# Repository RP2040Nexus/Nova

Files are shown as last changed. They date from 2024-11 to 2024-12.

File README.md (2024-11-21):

# Nova



Nova is a super tiny [RP2040](https://www.raspberrypi.com/products/rp2040/) board featuring an integrated 7x10 addressable LED matrix. This project aims to provide an easy-to-use platform for creating interactive and visually engaging projects.

## Table of Contents

- [Features](#features)
- [Getting Started](#getting-started)
- [Arduino IDE Installation](#arduino-ide-installation)
- [Pinouts](#pinouts)

## Features

- Compact size: Easy to integrate into various projects
- [RP2040](https://www.raspberrypi.com/products/rp2040/) microcontroller: Powerful and efficient
- Integrated 7x10 addressable LED matrix ([WS2812-1010](https://www.mouser.com/datasheet/2/744/WS2812B_1010_DATASHEET-3314306.pdf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))

## Getting Started

To get started with Nova, you'll need the following:

- [Nova Board](link_to_Nova_Product_Page)
- [Arduino IDE](https://www.arduino.cc/en/software)
- Compatible power source (USB Type-C, battery, etc.)

## Pinouts
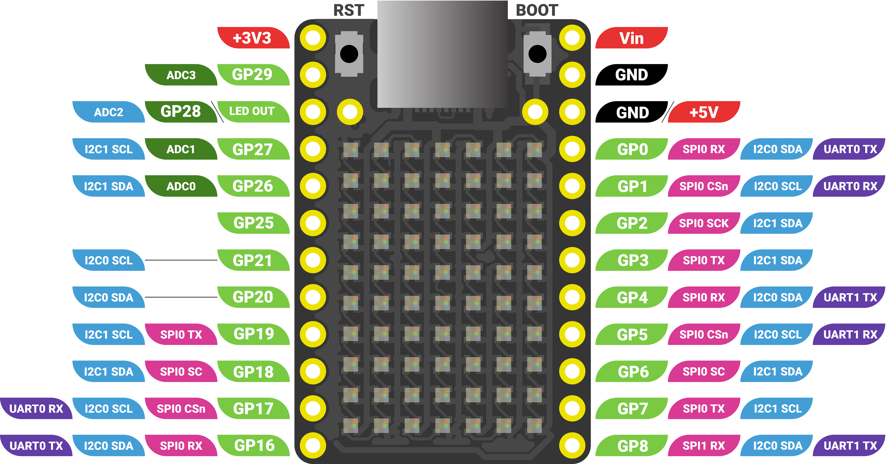
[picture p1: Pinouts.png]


## Arduino IDE Installation

### Adding Nova Board to Arduino IDE

1. **Open Arduino IDE**: Launch the Arduino IDE on your computer.

2. **Open Preferences**: 
   - Go to `File` -> `Preferences` (or `Arduino IDE` -> `Preferences` on macOS).

3. **Add Board URL**:
   - In the Preferences window, find the `Additional Boards Manager URLs` field. 
   - Add the following URL to the field:
     ```
     https://github.com/earlephilhower/arduino-pico/releases/download/global/package_rp2040_index.json
     ```
   - If there are already other URLs, separate them with commas.

4. **Open Boards Manager**:
   - Go to `Tools` -> `Board` -> `Boards Manager`.

5. **Install RP2040 Core**:
   - In the Boards Manager window, type `RP2040` in the search box.
   - Look for `Raspberry Pi Pico/RP2040 by Earle Philhower` and click the `Install` button.

6. **Select the Nova Board**:
   - Once the installation is complete, go to `Tools` -> `Board` and select `Raspberry Pi Pico`.

7. ### Install Required Libraries

- It is recommended to use the **FastLED** library for controlling the LED matrix.

#### Installing FastLED Library

1. **Open Library Manager**:
   - Go to `Sketch` -> `Include Library` -> `Manage Libraries...`.

2. **Search for FastLED**:
   - In the Library Manager window, type `FastLED` in the search bar.

3. **Install FastLED**:
   - Find the **FastLED** library ([Repo](https://github.com/FastLED/FastLED)) and click the `Install` button.
  
#### Using FastLED with Nova

Here’s a basic example of how to use the FastLED library to control a single LED on your Nova board:

```cpp
#include <FastLED.h>

#define LED_PIN     22    // Data pin connected to LED0 (GP22)
#define NUM_LEDS    1      // Total number of LEDs (only LED0)

CRGB leds[NUM_LEDS];

void setup() {
    FastLED.addLeds<WS2812, LED_PIN, GRB>(leds, NUM_LEDS);
    FastLED.setBrightness(10); // Set brightness to 10 out of 255
}

void loop() {
    // Example: Set LED0 to red color
    leds[0] = CRGB::Red;
    FastLED.show();
    delay(1000);
    
    // Example: Turn off LED0
    leds[0] = CRGB::Black;
    FastLED.show();
    delay(1000);
}

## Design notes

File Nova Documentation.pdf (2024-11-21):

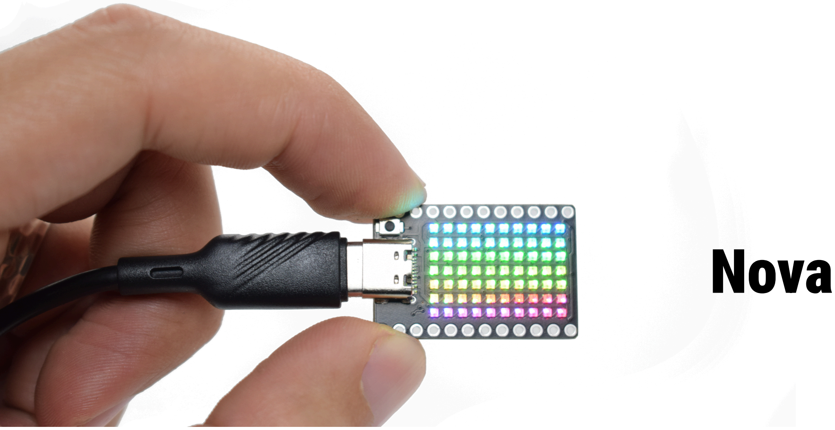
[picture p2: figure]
Nova

## 1. Introduction

The Nova board is an RP2040-based development board designed for engineers, developers, and embedded enthusiasts. With its powerful dual-core ARM Cortex M0+ processor and integrated 7x10 LED matrix, Nova offers a compact and versatile platform for various applications.

The board is open-source hardware, making it easy to customize and extend for your specific needs.

## 2. Features

- Microcontroller: Raspberry Pi RP2040 with dual ARM Cortex M0+ cores running up to 133 MHz.
- Memory: 264KB of SRAM, with support for external flash 16M-bit (2M-byte).
- 7x10 LED Matrix: Integrated with 70 RGB LEDs (addressable WS2812).
- GPIO: Accessible for various I/O purposes.
- Power Input: Via USB Type-C or external power.
- Connectivity: USB and various standard GPIO pins for communication protocols (I2C, SPI, UART).
- Open-source: Fully customizable hardware with publicly available schematics and examples.

## 3. Getting Started

### 3.1 Setting Up Your Development Environment

To start developing with the Nova board, follow these steps:

1. Install the Arduino IDE (https://www.arduino.cc/en/software) (or VSCode with the PlatformIO extension).
- Download the latest version from Arduino's website.
- For PlatformIO, follow the guide here. (https://docs.platformio.org/en/latest/platforms/raspberrypi.html)
2. Install the RP2040 Board Package:
- In the Arduino IDE, go to File > Preferences.
- Under Additional Boards Manager URLs, paste this URL:

https://github.com/earlephilhower/arduino-pico/releases/download/global/package_rp2040_index.json

- Open the Boards Manager and search for "RP2040." Install the package.
3. Install the FastLED Library:
- In the Arduino IDE, go to Sketch > Include Library > Manage Libraries.
- Search for "FastLED" and install it, (any other suitable library for the WS2812 LEDs can also be used such as Neopixel). (https://github.com/adafruit/Adafruit_NeoPixel)
4. Connect the Nova Board:
- Plug in the Nova board via the USB Type-C connector.
- Select the Nova board from the Tools > Board menu in the Arduino IDE.
- Choose the correct port under Tools > Port.

### 3.2 Hello World: Blink Example

Let's begin with a simple LED blink example:

#include <FastLED.h> // Include the FastLED library to control the LED matrix

#define DATA_PIN 22 // Define the pin where the LED matrix is connected (GPIO22)

#define NUM_LEDS 70 // Define the number of LEDs in the matrix (7x10 = 70)

CRGB leds[NUM_LEDS]; // Create an array to store the color data for each LED

void setup() {
// Initialize the LED matrix using the NEOPIXEL type and link it to the data pin
// FastLED.addLeds<CHIPSET, DATA_PIN>(led array, number of LEDs); FastLED.addLeds<NEOPIXEL, DATA_PIN>(leds, NUM_LEDS);
}

void loop() {
leds[0] = CRGB::Red; | // Set LED 0 (top-right corner) to red
FastLED.show(); | // Send the data to the LED matrix to display the
change
delay(500); | // Wait for 500 milliseconds (half a second)

leds[0] = CRGB::Black; // Turn off LED 0 (set it to black)

FastLED.show(); | // Update the LED matrix to show the change
delay(500); | // Wait for 500 milliseconds before repeating the
loop
}

Upload the code to your Nova board, and you should see the first LED (top right corner) blinking!

## 4. LED Matrix Layout

The Nova board comes with a 7x10 LED matrix. Here’s how the LEDs are arranged:

- Rows: The matrix is divided into rows, each containing 10 LEDs.
- Addressing: The LEDs are numbered from 0 to 69. The first row (LED0 to LED9) runs from right to left, while the second row (LED10 to LED10) runs from left to right, and so on.

Here's a quick reference:

LED9 | LED8 | LED7 | LED6 | LED5 | LED4 | LED3 | LED2 | LED1 | LED0
LED10 | LED11 | LED12 | LED13 | LED14 | LED15 | LED16 | LED17 | LED18 | LED19
LED29 | LED28 | LED27 | LED26 | LED25 | LED24 | LED23 | LED22 | LED21 | LED20
LED30 | LED31 | LED32 | LED33 | LED34 | LED35 | LED36 | LED37 | LED38 | LED39
LED49 | LED48 | LED47 | LED46 | LED45 | LED44 | LED43 | LED42 | LED41 | LED40
LED50 | LED51 | LED52 | LED53 | LED54 | LED55 | LED56 | LED57 | LED58 | LED59
LED69 | LED68 | LED67 | LED66 | LED65 | LED64 | LED63 | LED62 | LED61 | LED60

### 4.1 Displaying Custom Patterns

You can use the FastLED library to control the matrix. Here's an example to display the letter 'C' on the left side of the matrix:

#include <FastLED.h>

#define DATA_PIN 22

#define NUM_LEDS 70

CRGB leds[NUM_LEDS];

void setup() {
FastLED.addLeds<NEOPIXEL, DATA_PIN>(leds, NUM_LEDS); FastLED.clear(); // Clear the LED matrix
}

void loop() {
displayLetterC(); // Display the smaller letter 'C' on the matrix
FastLED.show(); | // Update the LED matrix
delay(5000); | // Hold the letter 'C' for 5 seconds
}

void displayLetterC() {
// Small 'C' that fits in 4 rows and 3 columns

// Left vertical column of 'C'
leds[9] = CRGB::Green; // Row 0
leds[10] = CRGB::Green; // Row 1 leds[29] = CRGB::Green; // Row 2 leds[30] = CRGB::Green; // Row 3

// Top part of 'C' (Row 0) leds[8] = CRGB::Green;
leds[7] = CRGB::Green;

// Bottom part of 'C' (Row 3) leds[31] = CRGB::Green;
leds[32] = CRGB::Green;
}
LED9 | LED8 | LED7 | LED6 | LED5 | LED4 | LED3 | LED2 | LED1 | LED0
LED10 | LED11 | LED12 | LED13 | LED14 | LED15 | LED16 | LED17 | LED18 | LED19
LED29 | LED28 | LED27 | LED26 | LED25 | LED24 | LED23 | LED22 | LED21 | LED20
LED30 | LED31 | LED32 | LED33 | LED34 | LED35 | LED36 | LED37 | LED38 | LED39
LED49 | LED48 | LED47 | LED46 | LED45 | LED44 | LED43 | LED42 | LED41 | LED40
LED50 | LED51 | LED52 | LED53 | LED54 | LED55 | LED56 | LED57 | LED58 | LED59
LED69 | LED68 | LED67 | LED66 | LED65 | LED64 | LED63 | LED62 | LED61 | LED60

## 6. Pinout

- Data Pin for LED Matrix: GPIO22
- Other key GPIO pins are exposed for various I/O tasks. Please refer to the pinout diagram for detailed pin functions:

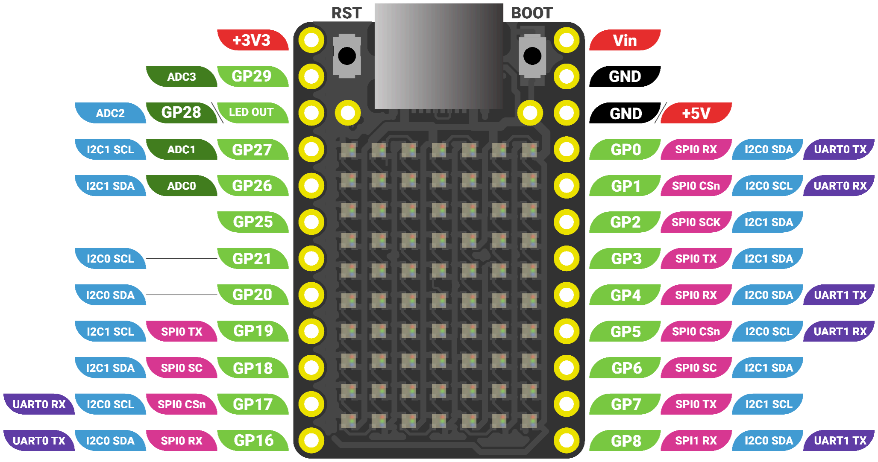
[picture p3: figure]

## 7. Powering the Board and Power Consumption

Power Regulation:

- Nova has two regulators: a buck converter and an LDO (linear regulator).
- The buck converter handles input voltages from 7VDC to 18VDC via the Vin pin and provides 5VDC for the circuit, which is needed for the addressable LEDs.
- The LDO takes the 5VDC from either the buck converter or USB and regulates it down to 3.3VDC for the RP2040 and other 3.3V components.

Powering the Board:

- The board can be powered via:
- Vin pin: Accepts 7-18VDC.
- +5V pin: Accepts 4.8-5.2VDC.
- +3V3 pin is not meant to power the whole board, only the MCU (without LEDs).

Power Output from +5V Pin:

- When powered by the Vin pin, the +5V pin can provide up to 1.2A.
- When powered by USB, the +5V pin can provide up to 150mA.

+3V3 Pin:

- The recommended maximum current draw from the +3V3 pin is 150mA in all cases.

Power Consumption
The Nova board consumes approximately 9 watts when all LEDs are at full brightness in white color. It’s recommended to avoid running all LEDs at maximum brightness for extended periods, as this can cause the board to overheat, potentially leading to
damage to the board or its components.

## 8. Schematics and Hardware

The Nova board is open-source hardware. You can find the schematics, PCB design files, and BOM (Bill of Materials) on our GitHub (https://github.com/VccLabs/Nova) repository.

## 9. Troubleshooting

Common Issues

1. Board not recognized:
- Ensure that the USB cable is working and data-capable.
- Check if the correct port and board are selected in the Arduino IDE.
2. LEDs not lighting up:
- Verify that the data pin is identified in the code properly (GPIO22).
- Make sure the FastLED library is installed and included in your sketch (any other suitable library for the WS2812 LEDs can also be used such as Neopixel). (https://github.com/adafruit/Adafruit_NeoPixel)
- You can enter bootloader mode using the ‘Boot’ button. To do this, hold down the 'Boot' button (located to the right of the USB port) while connecting the board to your PC via USB. This will put the board into bootloader mode and open a mass storage window on your computer. This is useful if the board is not being detected by the PC.

## 10. Contact & Support

For further questions or support, you can reach us at support@vcclabs.com. Join our community on GitHub and check out the forums for more resources and user projects.

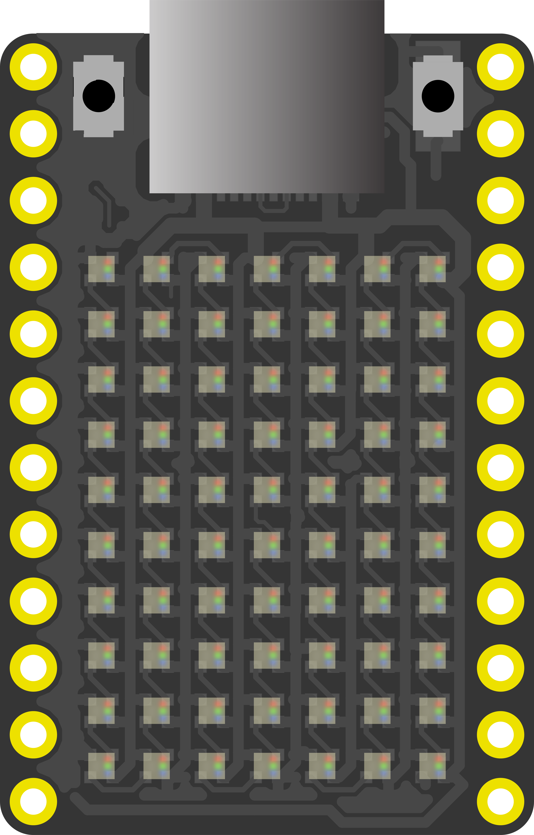
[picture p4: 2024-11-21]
Illustrations/Board Illustration.png

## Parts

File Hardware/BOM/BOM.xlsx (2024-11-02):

Comment | Designator | Footprint | Manufacturer Part #
Miltilayer Ceramic Capacitor 100nF | C1,C2,C9 | 0402 | CL05B104KB54PNC
Miltilayer Ceramic Capacitor 10uF | C3,C4,C5,C6,C7,C11,C33 | 0603 | GRM188R6YA106MA73D
Miltilayer Ceramic Capacitor 27pF | C8,C10 | 0402 | CC0402JRNPO9BN270
Miltilayer Ceramic Capacitor 120pF | C12 | 0402 | CC0402JRNPO9BN121
Miltilayer Ceramic Capacitor 12nF | C13 | 0402 | GRM155R71H123KA12D
SMD,1x1mm RGB LEDs(Built-in IC) ROHS | D1,D2,D3,D4,D5,D6,D7,D8,D9,D10,D11,D12,D13,D14,D15,D16,D17,D18,D19,D20,D21,D22,D23,D24,D25,D26,D27,D28,D29,D30,D31,D32,D33,D34,D35,D36,D37,D38,D39,D40,D41,D42,D43,D44,D45,D46,D47,D48,D49,D50,D51,D52,D53,D54,D55,D56,D57,D58,D59,D60,D61,D62,D63,D64,D65,D66,D67,D68,D69,D70 | SMD,1x1mm | XL-1010RGBC-WS2812B
USON-8-EP(2x3) NOR FLASH ROHS | IC1 | USON-8-EP(2x3) | W25Q16JVUXIQ
1A 4.7uH ±20% 130mΩ 1008 Inductors (SMD) ROHS | L1,L2,L3 | 1008 | MLP2520S4R7MT0S1
50V 220mA 3.5Ω@10V,220mA 360mW 1.5V@1mA 1PCSNChannel SOT-23 MOSFETs ROHS | Q3 | SOT-23 | BSS138
SMD Chip Resistor 3.74K | R1 | 0402 | 0402WGF3741TCE
SMD Chip Resistor 1K | R3,R4 | 0402 | 0402WGF1001TCE
SMD Chip Resistor 10K | R5,R8,R9,R32 | 0402 | 0402WGF1002TCE
SMD Chip Resistor 27.4 | R6,R7 | 0402 | ARG02FTC27R4
SMD Chip Resistor 220K | R14 | 0402 | RC0402FR-07220KL
SMD Chip Resistor 43.2K | R15 | 0402 | RT0402FRE0743K2L
SMD Chip Resistor 100K | R16 | 0402 | RC0402FR-07100KL
SMD Chip Resistor 19.1K | R17 | 0402 | 0402WGF1912TCE
SMD Chip Resistor 51.1 | R18 | 0402 | SCR0402F51R1
SMD Chip Resistor 143K | R19 | 0402 | FRC0402F1433TS
2.5mm 1.6mm Round Button 50mA Standing paste 3mm SPST 153gf 12V SMD,2.5x3mm Tactile Switches ROHS | S1 | SMD,2.5x3mm | B3U-1000P
Step-down type Adjustable 800mV~24V 3A 4.5V~28V VSON-10-EP(3x3) DC-DC Converters ROHS | U1 | VSON-10-EP(3x3) | TPS54335ADRCR
65dB@(100Hz,1kHz) 600mA Fixed 3.3V Positive electrode 6V SOT-25-5 Voltage Regulators - Linear, Low Drop Out (LDO) Regulators ROHS | U2 | SOT-25-5 | AP2112K-3.3TRG1
264KB 30 133MHz LQFN-56(7x7) Microcontrollers (MCU/MPU/SOC) ROHS | U3 | LQFN-56(7x7) | RP2040
TYPEC-304-ACP16 | USBC | TYPEC-304-ACP16 | TYPEC-304-ACP16
12MHz SMD Crystal Resonator 18pF 150Ω ±10ppm ±30ppm -40℃~+85℃ SMD2520-4P Crystals ROHS | Y2 | SMD2520-4P | 2TJ412000XYGBC

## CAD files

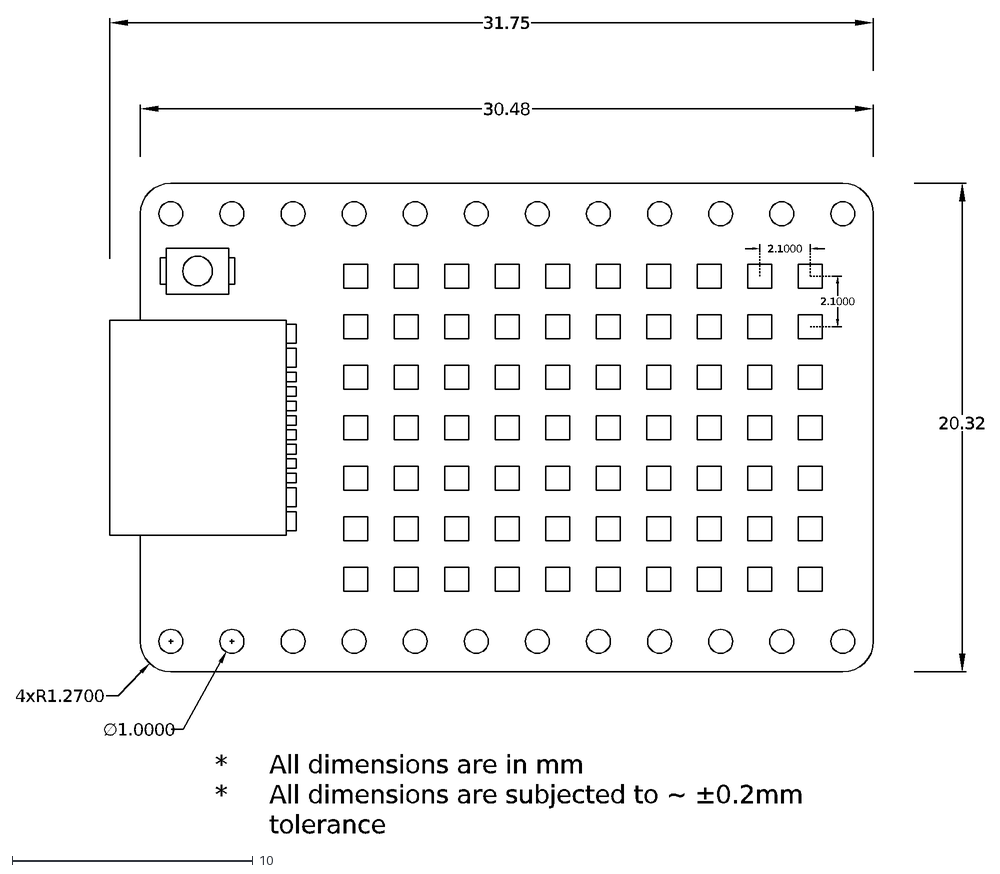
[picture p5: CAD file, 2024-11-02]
Hardware/Board Dimensions & DXF/Board DXF.dxf
30.48
20.32
4xR1.2700
∅1.0000
2.1000
31.75
* All dimensions are in mm * All dimensions are subjected to ~ ±0.2mm tolerance

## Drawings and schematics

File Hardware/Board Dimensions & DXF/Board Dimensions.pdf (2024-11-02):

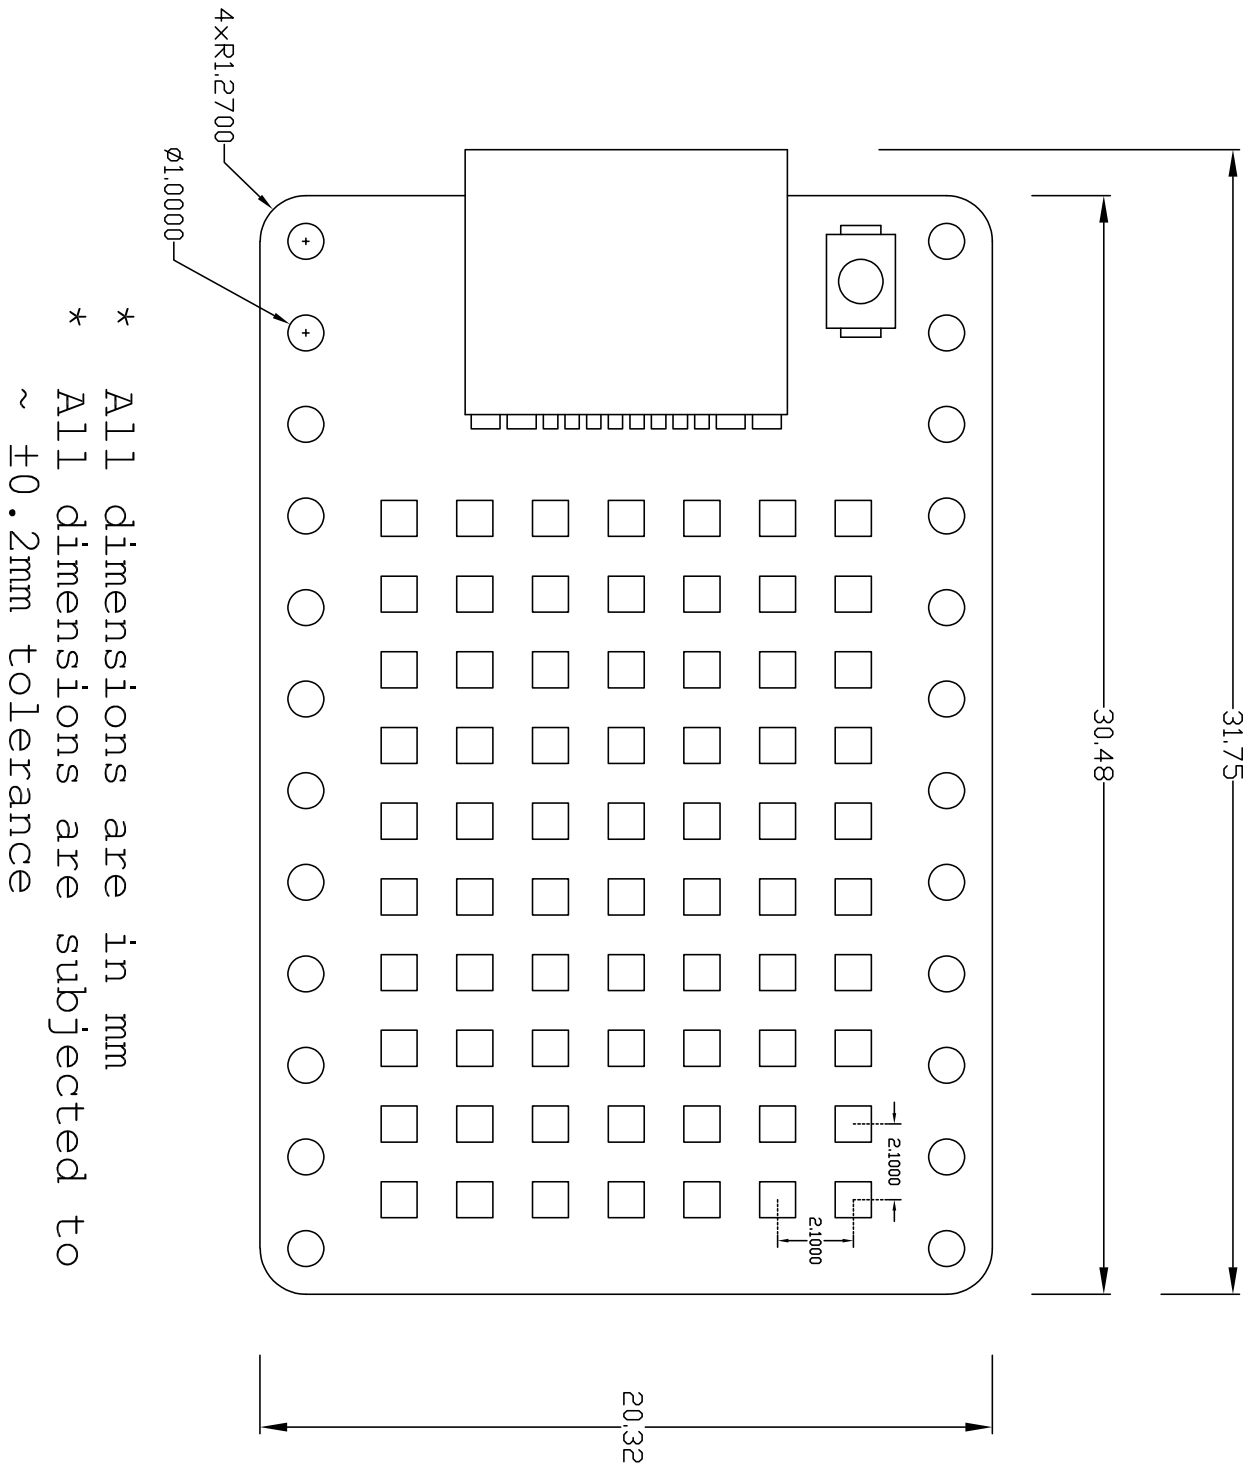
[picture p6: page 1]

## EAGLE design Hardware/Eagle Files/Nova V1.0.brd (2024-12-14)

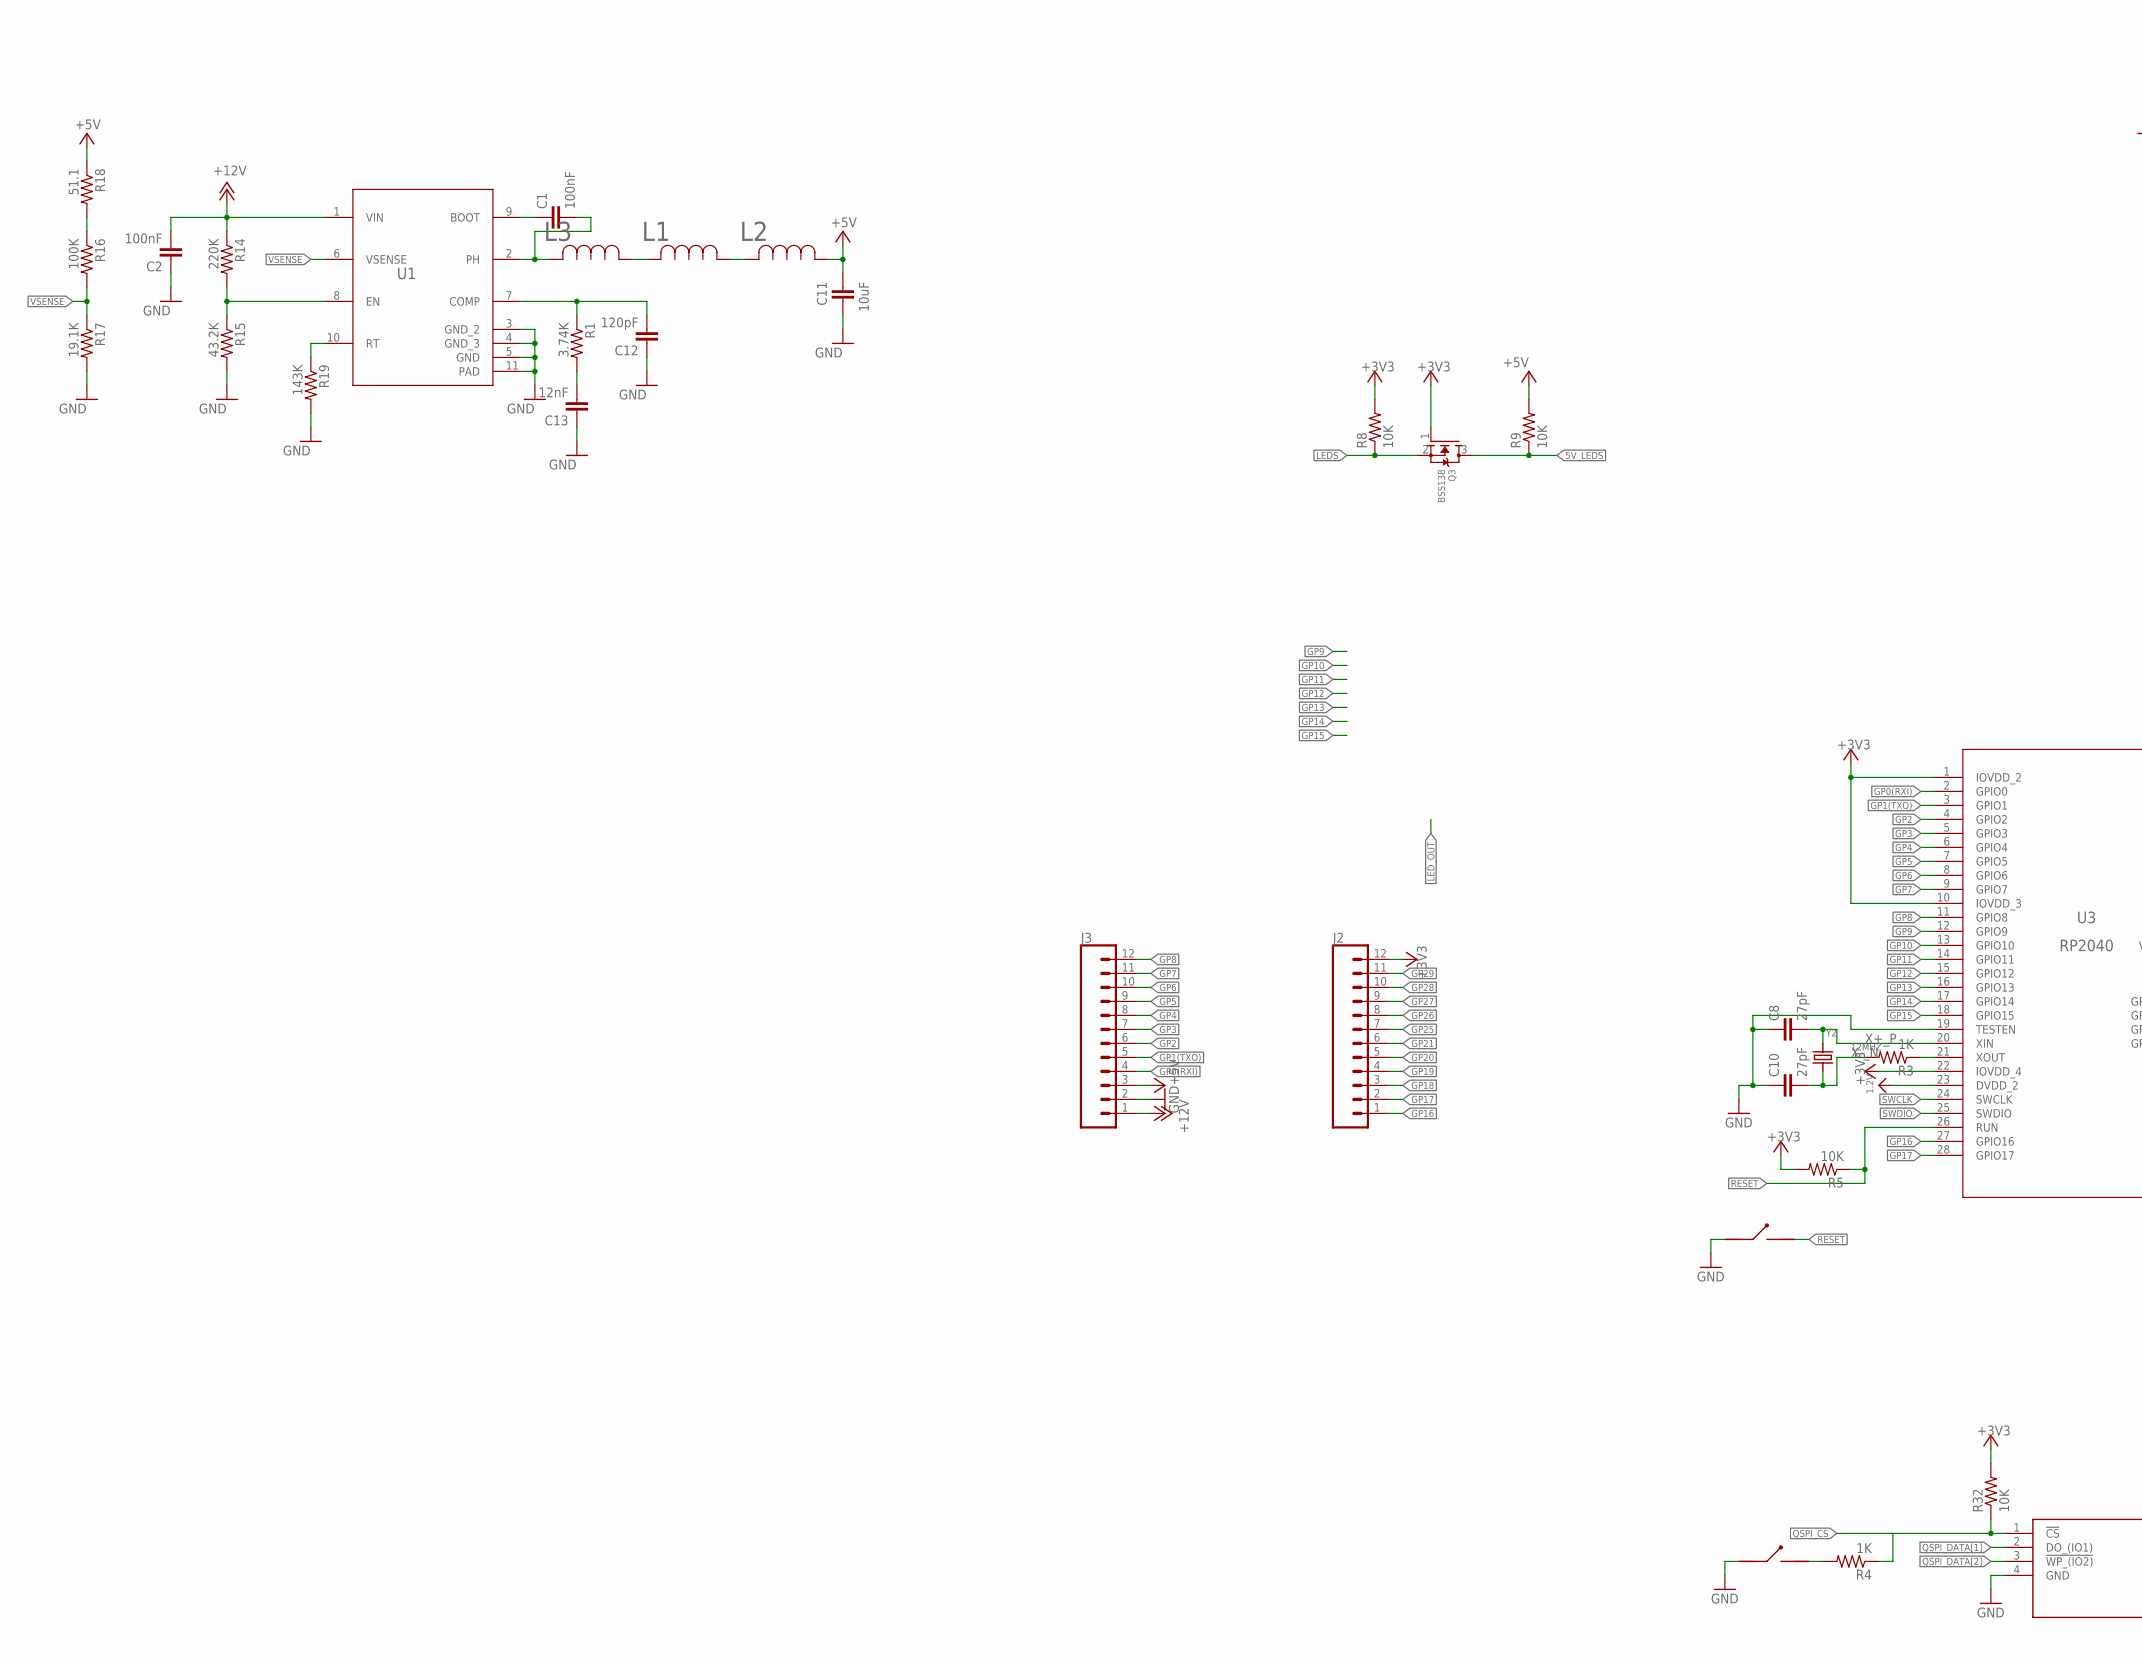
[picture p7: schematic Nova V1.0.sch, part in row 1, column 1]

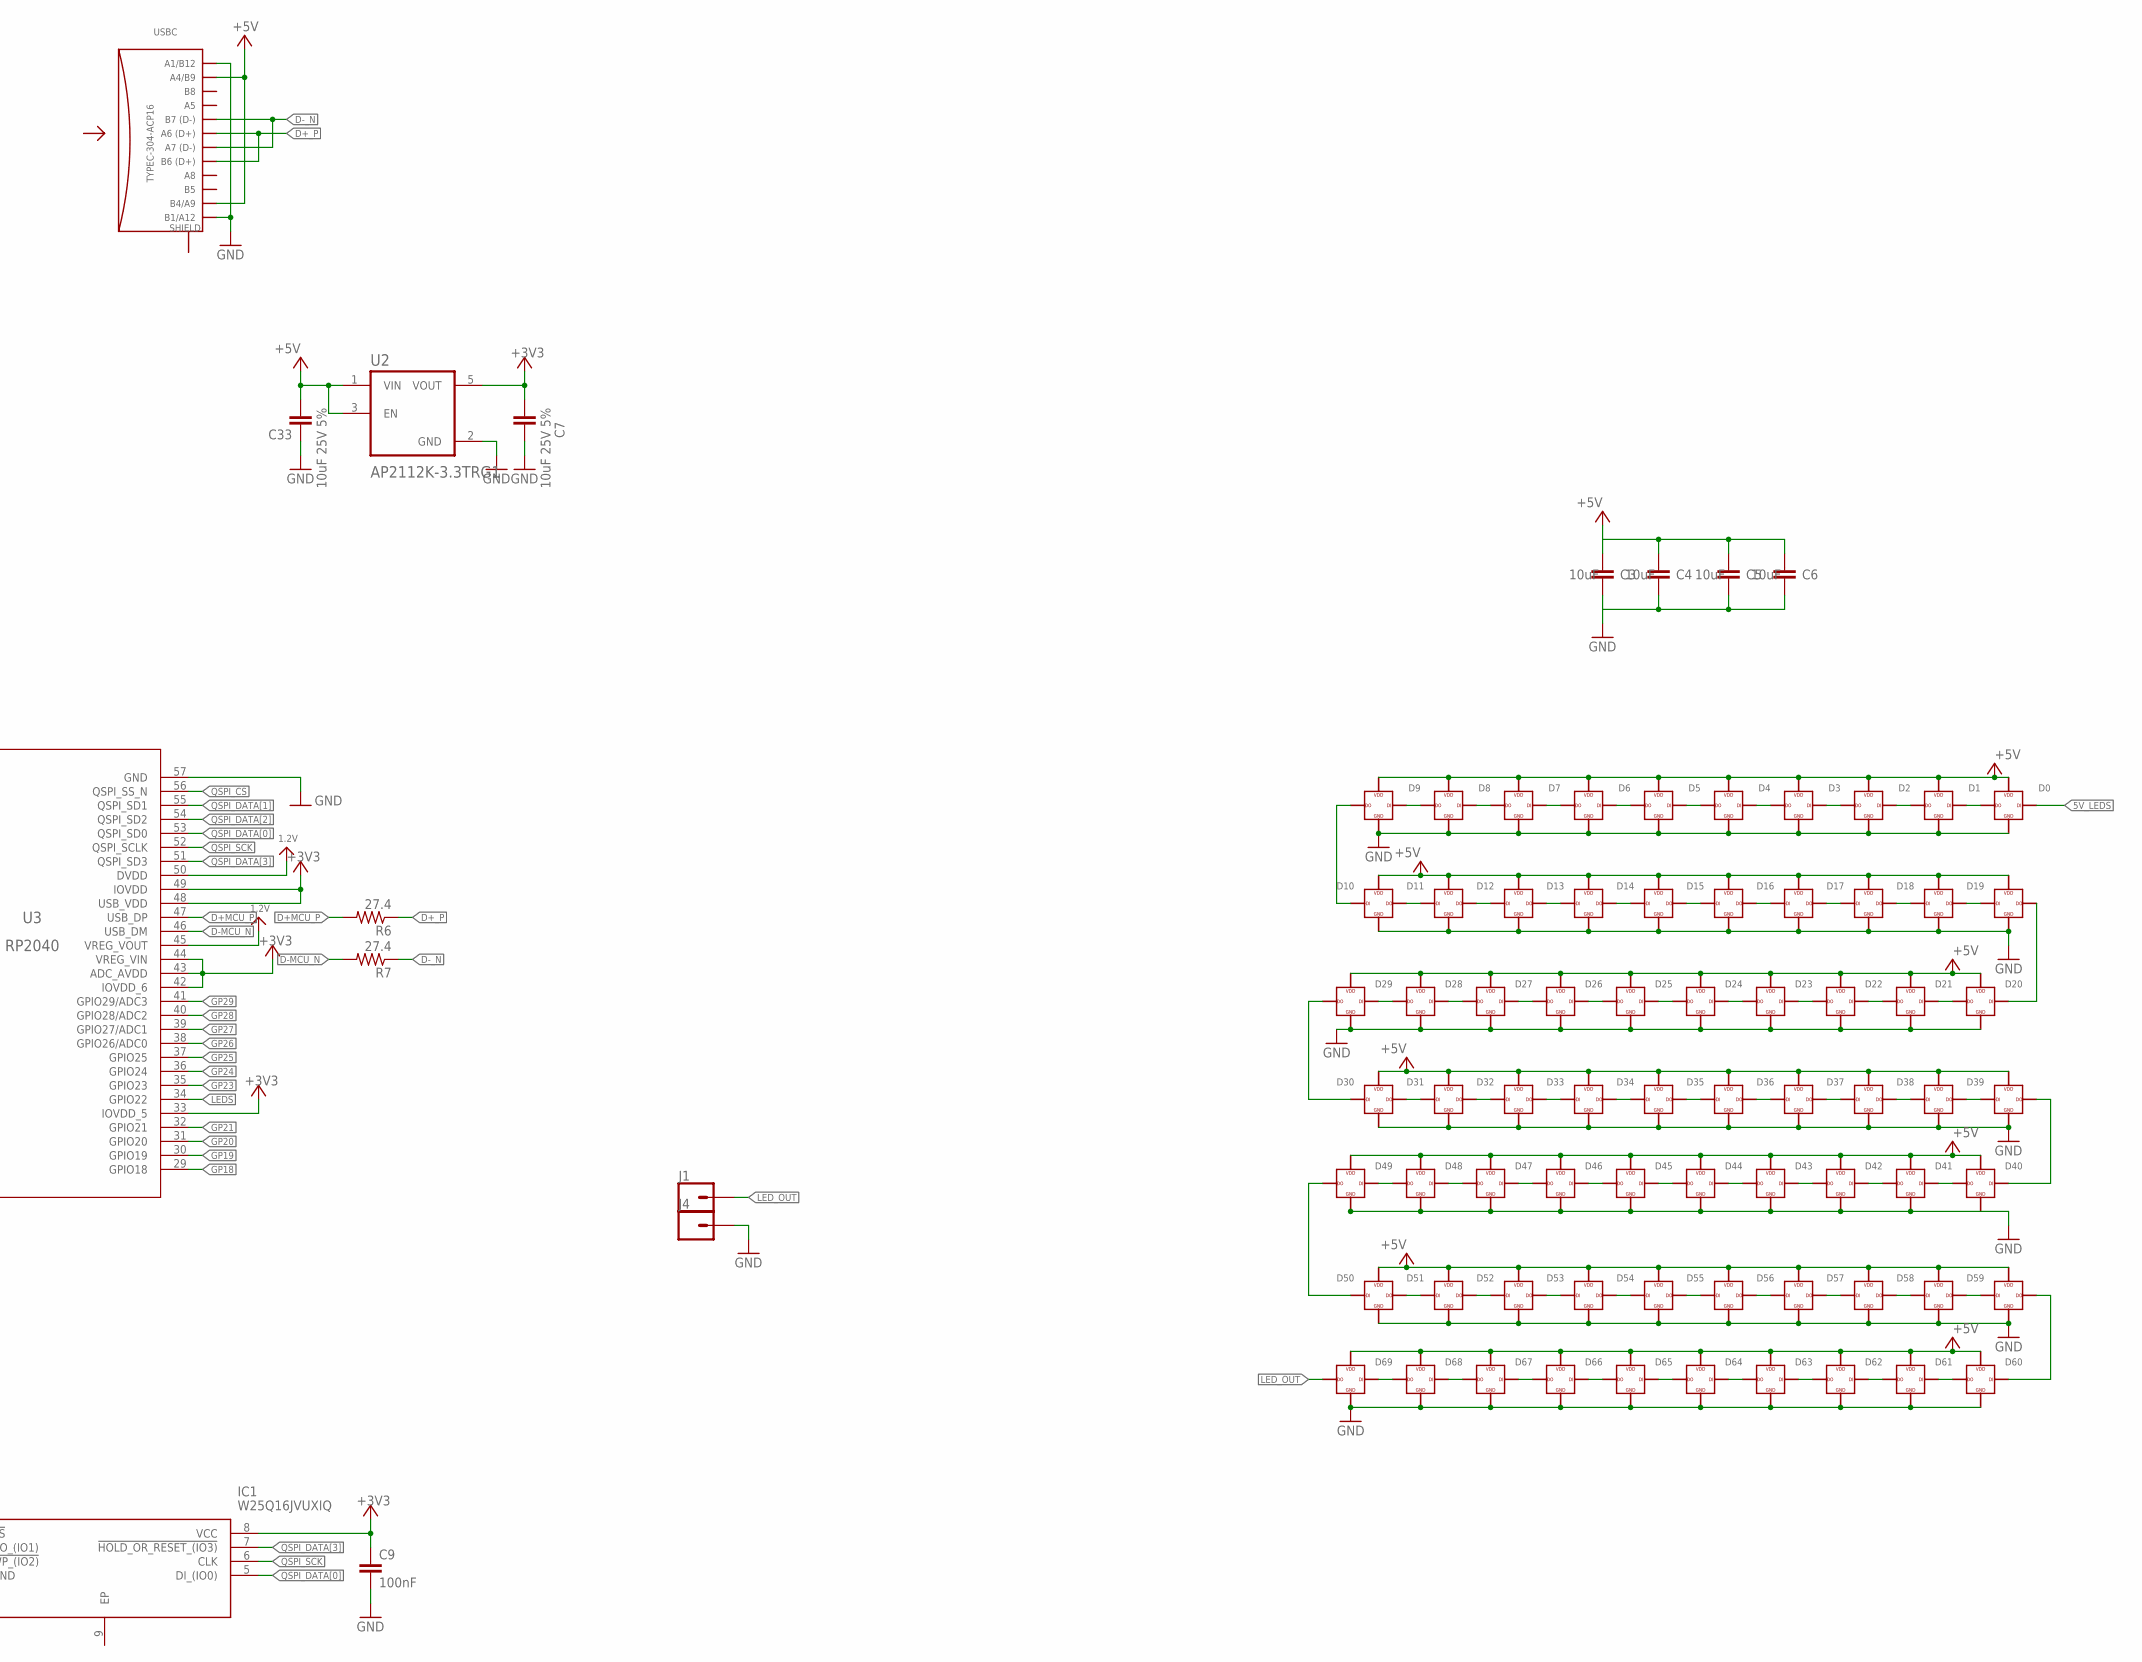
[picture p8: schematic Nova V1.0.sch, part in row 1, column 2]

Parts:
C1, C2, C9: 100nF; 0402-TIGHT
C3, C4, C5, C6, C11: 10uF; C0603
C7, C33: 10uF 25V 5%; C0603
C8, C10: 27pF; 0402-TIGHT
C12: 120pF; 0402-TIGHT
C13: 12nF; 0402-TIGHT
D0, D1, D2, D3, D4, D5, D6, D7, D8, D9, D10, D11, D12, D13, D14, D15, D16, D17, D18, D19, D20, D21, D22, D23, D24, D25, D26, D27, D28, D29, D30, D31, D32, D33, D34, D35, D36, D37, D38, D39, D40, D41, D42, D43, D44, D45, D46, D47, D48, D49, D50, D51, D52, D53, D54, D55, D56, D57, D58, D59, D60, D61, D62, D63, D64, D65, D66, D67, D68, D69: XL-1010RGBC-WS2812B
IC1: W25Q16JVUXIQ; SON50P300X200X60-9N
J1, J4: CONN_01; 1X01
J2, J3: CONN_12; 1X12
L1, L2, L3: MLP2520S4R7MT0S1IND_2520_TDK-L; IND_2520_TDK-L
Q3: BSS138; SOT23
R1: 3.74K; R0402
R3, R4: 1K; R0402
R5, R8, R9, R32: 10K; R0402
R6, R7: 27.4; R0402
R14: 220K; R0402
R15: 43.2K; R0402
R16: 100K; R0402
R17: 19.1K; R0402
R18: 51.1; R0402
R19: 143K; R0402
S1, S2: B3U-1000P
U1: TPS54335ADRCRDRC0010J_NV; DRC0010J_NV
U2: AP2112K-3.3TRG1; SOT95P285X140-5N
U3: RP2040; IC57_RP2040
USBC: TYPEC-304-ACP16
Y2: 12MHZ; CRYSTAL_2.5X2

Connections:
1.2V: U3.23 (DVDD_2), U3.45 (VREG_VOUT), U3.50 (DVDD)
5V_LEDS: D0.4, Q3.3 (D), R9.1
+3V3: C7.2, C9.1, IC1.8 (VCC), J2.12, Q3.1 (G), R5.2, R8.2, R32.2, U2.5 (VOUT), U3.1 (IOVDD_2), U3.10 (IOVDD_3), U3.22 (IOVDD_4), U3.33 (IOVDD_5), U3.42 (IOVDD_6), U3.43 (ADC_AVDD), U3.44 (VREG_VIN), U3.48 (USB_VDD), U3.49 (IOVDD)
+5V: C3.1, C4.1, C5.1, C6.1, C11.2, C33.2, D0.2, D1.2, D2.2, D3.2, D4.2, D5.2, D6.2, D7.2, D8.2, D9.2, D10.2, D11.2, D12.2, D13.2, D14.2, D15.2, D16.2, D17.2, D18.2, D19.2, D20.2, D21.2, D22.2, D23.2, D24.2, D25.2, D26.2, D27.2, D28.2, D29.2, D30.2, D31.2, D32.2, D33.2, D34.2, D35.2, D36.2, D37.2, D38.2, D39.2, D40.2, D41.2, D42.2, D43.2, D44.2, D45.2, D46.2, D47.2, D48.2, D49.2, D50.2, D51.2, D52.2, D53.2, D54.2, D55.2, D56.2, D57.2, D58.2, D59.2, D60.2, D61.2, D62.2, D63.2, D64.2, D65.2, D66.2, D67.2, D68.2, D69.2, J3.3, L2.1, R9.2, R18.1, U2.1 (VIN), U2.3 (EN), USBC.A4/B9, USBC.B4/A9
+12V: C2.2, J3.1, R14.1, U1.1 (VIN)
D+MCU_P: R6.2, U3.47 (USB_DP)
D+_P: R6.1, USBC.A6, USBC.B6
D-MCU_N: R7.2, U3.46 (USB_DM)
D-_N: R7.1, USBC.A7, USBC.B7
GND: C2.1, C3.2, C4.2, C5.2, C6.2, C7.1, C8.1, C9.2, C10.1, C11.1, C12.1, C13.1, C33.1, D0.3, D1.3, D2.3, D3.3, D4.3, D5.3, D6.3, D7.3, D8.3, D9.3, D10.3, D11.3, D12.3, D13.3, D14.3, D15.3, D16.3, D17.3, D18.3, D19.3, D20.3, D21.3, D22.3, D23.3, D24.3, D25.3, D26.3, D27.3, D28.3, D29.3, D30.3, D31.3, D32.3, D33.3, D34.3, D35.3, D36.3, D37.3, D38.3, D39.3, D40.3, D41.3, D42.3, D43.3, D44.3, D45.3, D46.3, D47.3, D48.3, D49.3, D50.3, D51.3, D52.3, D53.3, D54.3, D55.3, D56.3, D57.3, D58.3, D59.3, D60.3, D61.3, D62.3, D63.3, D64.3, D65.3, D66.3, D67.3, D68.3, D69.3, IC1.4 (GND), J3.2, J4.1, R15.2, R17.2, R19.2, S1.1, S2.1, U1.3 (GND_2), U1.4 (GND_3), U1.5 (GND), U1.11 (PAD), U2.2 (GND), U3.19 (TESTEN), U3.57 (GND), USBC.A1/B12, USBC.B1/A12
GP0(RXI): J3.4, U3.2 (GPIO0)
GP1(TXO): J3.5, U3.3 (GPIO1)
GP2: J3.6, U3.4 (GPIO2)
GP3: J3.7, U3.5 (GPIO3)
GP4: J3.8, U3.6 (GPIO4)
GP5: J3.9, U3.7 (GPIO5)
GP6: J3.10, U3.8 (GPIO6)
GP7: J3.11, U3.9 (GPIO7)
GP8: J3.12, U3.11 (GPIO8)
GP9: U3.12 (GPIO9)
GP10: U3.13 (GPIO10)
GP11: U3.14 (GPIO11)
GP12: U3.15 (GPIO12)
GP13: U3.16 (GPIO13)
GP14: U3.17 (GPIO14)
GP15: U3.18 (GPIO15)
GP16: J2.1, U3.27 (GPIO16)
GP17: J2.2, U3.28 (GPIO17)
GP18: J2.3, U3.29 (GPIO18)
GP19: J2.4, U3.30 (GPIO19)
GP20: J2.5, U3.31 (GPIO20)
GP21: J2.6, U3.32 (GPIO21)
GP23: U3.35 (GPIO23)
GP24: U3.36 (GPIO24)
GP25: J2.7, U3.37 (GPIO25)
GP26: J2.8, U3.38 (GPIO26/ADC0)
GP27: J2.9, U3.39 (GPIO27/ADC1)
GP28: J2.10, U3.40 (GPIO28/ADC2)
GP29: J2.11, U3.41 (GPIO29/ADC3)
LEDS: Q3.2 (S), R8.1, U3.34 (GPIO22)
LED_OUT: D69.1, J1.1
unnamed: D0.1, D1.4
unnamed: D1.1, D2.4
unnamed: D2.1, D3.4
unnamed: D3.1, D4.4
unnamed: D4.1, D5.4
unnamed: D5.1, D6.4
unnamed: D6.1, D7.4
unnamed: D7.1, D8.4
unnamed: D8.1, D9.4
unnamed: D9.1, D10.4
unnamed: D10.1, D11.4
unnamed: D11.1, D12.4
unnamed: D12.1, D13.4
unnamed: D13.1, D14.4
unnamed: D14.1, D15.4
unnamed: D15.1, D16.4
unnamed: D16.1, D17.4
unnamed: D17.1, D18.4
unnamed: D18.1, D19.4
unnamed: D19.1, D20.4
unnamed: D20.1, D21.4
unnamed: D21.1, D22.4
unnamed: D22.1, D23.4
unnamed: D23.1, D24.4
unnamed: D24.1, D25.4
unnamed: D25.1, D26.4
unnamed: D26.1, D27.4
unnamed: D27.1, D28.4
unnamed: D28.1, D29.4
unnamed: D29.1, D30.4
unnamed: D30.1, D31.4
unnamed: D31.1, D32.4
unnamed: D32.1, D33.4
unnamed: D33.1, D34.4
unnamed: D34.1, D35.4
unnamed: D35.1, D36.4
unnamed: D36.1, D37.4
unnamed: D37.1, D38.4
unnamed: D38.1, D39.4
unnamed: D39.1, D40.4
unnamed: D40.1, D41.4
unnamed: D41.1, D42.4
unnamed: D42.1, D43.4
unnamed: D43.1, D44.4
unnamed: D44.1, D45.4
unnamed: D45.1, D46.4
unnamed: D46.1, D47.4
unnamed: D47.1, D48.4
unnamed: D48.1, D49.4
unnamed: D49.1, D50.4
unnamed: D50.1, D51.4
unnamed: D51.1, D52.4
unnamed: D52.1, D53.4
unnamed: D53.1, D54.4
unnamed: D54.1, D55.4
unnamed: D55.1, D56.4
unnamed: D56.1, D57.4
unnamed: D57.1, D58.4
unnamed: D58.1, D59.4
unnamed: D59.1, D60.4
unnamed: D60.1, D61.4
unnamed: D61.1, D62.4
unnamed: D62.1, D63.4
unnamed: D63.1, D64.4
unnamed: D64.1, D65.4
unnamed: D65.1, D66.4
unnamed: D66.1, D67.4
unnamed: D67.1, D68.4
unnamed: D68.1, D69.4
unnamed: R3.1, U3.21 (XOUT)
unnamed: R4.2, S1.2
unnamed: C1.1, U1.9 (BOOT)
unnamed: L1.2, L3.1
unnamed: L1.1, L2.2
unnamed: C13.2, R1.2
unnamed: C12.2, R1.1, U1.7 (COMP)
unnamed: R14.2, R15.1, U1.8 (EN)
unnamed: R16.1, R18.2
unnamed: R19.1, U1.10 (RT)
PH: C1.2, L3.2, U1.2 (PH)
QSPI_CS: IC1.1 (!CS), R4.1, R32.1, U3.56 (QSPI_SS_N)
QSPI_DATA[0]: IC1.5 (DI_(IO0)), U3.53 (QSPI_SD0)
QSPI_DATA[1]: IC1.2 (DO_(IO1)), U3.55 (QSPI_SD1)
QSPI_DATA[2]: IC1.3 (!WP_(IO2)), U3.54 (QSPI_SD2)
QSPI_DATA[3]: IC1.7 (!HOLD_OR_RESET_(IO3)), U3.51 (QSPI_SD3)
QSPI_SCK: IC1.6 (CLK), U3.52 (QSPI_SCLK)
RESET: R5.1, S2.2, U3.26 (RUN)
SWCLK: U3.24 (SWCLK)
SWDIO: U3.25 (SWDIO)
VSENSE: R16.2, R17.1, U1.6 (VSENSE)
X+_P: C8.2, U3.20 (XIN), Y2.3 (2)
X-_N: C10.2, R3.2, Y2.1

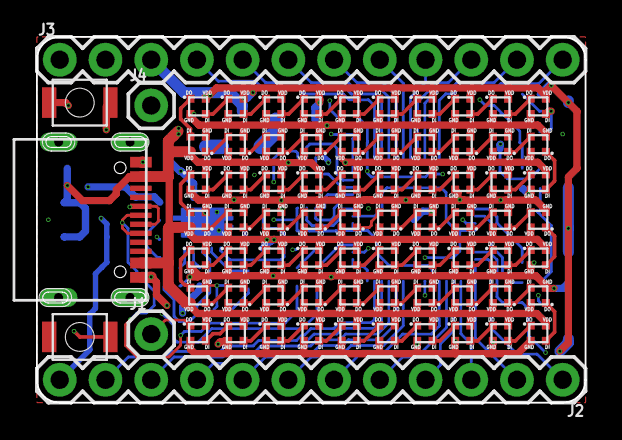
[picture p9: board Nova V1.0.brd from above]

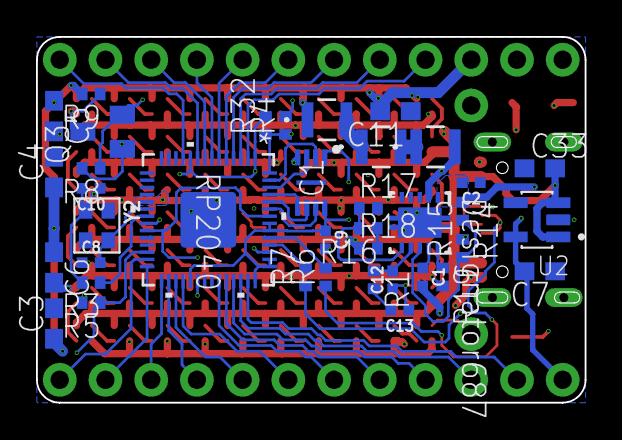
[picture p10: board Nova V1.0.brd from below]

Board: 4 copper layers, 30.5 x 20.3 mm, 115 parts (38 on the bottom side), 122 nets.

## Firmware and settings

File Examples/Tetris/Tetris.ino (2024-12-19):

/*
 * Tetris Game Example for Nova Board
 *
 * Button Connections:
 * - UP Button: connected to pin 2
 * - LEFT Button: connected to pin 3
 * - DOWN Button: connected to pin 4
 * - RIGHT Button: connected to pin 5
 * - RESET Button: connected to pin 6
 *
 * Note: External pull-down resistors are used with the buttons to ensure stable readings.
 *
 * License:
 * This project is open-source hardware and software, released under the MIT License.
 * See the LICENSE file for details.
 */


#include <FastLED.h>

#define LED_PIN 22
#define NUM_LEDS 70
#define BRIGHTNESS 10

CRGB leds[NUM_LEDS];

// Matrix layout
const int matrix[10][7] = {
    {69, 50, 49, 30, 29, 10, 9},
    {68, 51, 48, 31, 28, 11, 8},
    {67, 52, 47, 32, 27, 12, 7},
    {66, 53, 46, 33, 26, 13, 6},
    {65, 54, 45, 34, 25, 14, 5},
    {64, 55, 44, 35, 24, 15, 4},
    {63, 56, 43, 36, 23, 16, 3},
    {62, 57, 42, 37, 22, 17, 2},
    {61, 58, 41, 38, 21, 18, 1},
    {60, 59, 40, 39, 20, 19, 0}
};

// Button pins
const int upButtonPin = 2;
const int leftButtonPin = 3;
const int downButtonPin = 4;
const int rightButtonPin = 5;
const int generalButtonPin = 6;

// Tetromino shapes
const int shapes[7][4][1] = {
    // I
    {{1}, {1}, {1}, {1}},
    // O
    {{1}, {1}, {0}, {0}},
    // T
    {{0}, {1}, {1}, {0}},
    // J
    {{1}, {1}, {1}, {0}},
    // L
    {{0}, {0}, {1}, {1}},
    // S
    {{0}, {1}, {1}, {0}},
    // Z
    {{1}, {1}, {0}, {0}},
};

// Game variables
int currentShapeIndex;
int currentX, currentY;

// Game state
bool board[10][7] = {false};

unsigned long lastUpdate = 0; // Variable to store the last update time
const unsigned long updateInterval = 300; // Game update interval

const unsigned long debounceDelay = 250; // Debounce time in milliseconds
unsigned long lastPressTime[5] = {0}; // Array to store the last pressed time for each button

void setup() {
    Serial.begin(115200);
    FastLED.addLeds<WS2812, LED_PIN, GRB>(leds, NUM_LEDS).setCorrection(TypicalLEDStrip);
    FastLED.setBrightness(BRIGHTNESS);



    // Start a new game
    startNewGame();
}

void loop() {
    readButtons(); // Check for button presses

    unsigned long currentMillis = millis(); // Get the current time
    // Check if it's time to update the game state
    if (currentMillis - lastUpdate >= updateInterval) {
        moveDown(); // Move the piece down
        drawBoard(); // Draw the updated board
        
        lastUpdate = currentMillis; // Update the last update time
    }
    FastLED.show(); // Update the LED strip
}

void startNewGame() {
    // Reset the board state
    memset(board, false, sizeof(board)); // Clear the board
    resetPiece(); // Get a new piece
}



void readButtons() {
    unsigned long currentMillis = millis(); // Get the current time

    // Right button
    if (digitalRead(rightButtonPin) == HIGH && (currentMillis - lastPressTime[0] >= debounceDelay)) {
        lastPressTime[0] = currentMillis; // Update the last pressed time
        movePiece(1, 0); // Move right
    }

    // Left button
    if (digitalRead(leftButtonPin) == HIGH && (currentMillis - lastPressTime[1] >= debounceDelay)) {
        lastPressTime[1] = currentMillis; // Update the last pressed time
        movePiece(-1, 0); // Move left
    }

    // Up button (rotate piece - not implemented)
    if (digitalRead(upButtonPin) == HIGH && (currentMillis - lastPressTime[2] >= debounceDelay)) {
        lastPressTime[2] = currentMillis; // Update the last pressed time
        // Rotate piece (not implemented)
    }

    // Down button
    if (digitalRead(downButtonPin) == HIGH && (currentMillis - lastPressTime[3] >= debounceDelay)) {
        lastPressTime[3] = currentMillis; // Update the last pressed time
        moveDown(); // Move down
    }

    // General button (restart game)
    if (digitalRead(generalButtonPin) == HIGH && (currentMillis - lastPressTime[4] >= debounceDelay)) {
        lastPressTime[4] = currentMillis; // Update the last pressed time
        startNewGame(); // Restart the game
    }
}


void movePiece(int dx, int dy) {
    currentX += dx;
    currentY += dy;

    // Check for collisions
    if (checkCollision()) {
        currentX -= dx; // Undo move
        currentY -= dy; // Undo move
    }
}

void moveDown() {
    currentY++;
    if (checkCollision()) {
        currentY--; // Undo move
        lockPiece(); // Lock the piece
        resetPiece(); // Get a new piece
    }
}

void resetPiece() {
    currentShapeIndex = random(0, 7); // Choose a random shape
    currentX = 3; // Start in the middle
    currentY = 0; // Start at the top

    // Check for game over condition immediately after resetting
    if (checkCollision()) {
        startNewGame(); // Restart the game if collision with the top row occurs
    }
}

bool checkCollision() {
    for (int i = 0; i < 4; i++) {
        int ledX = currentX; 
        int ledY = currentY + (shapes[currentShapeIndex][i][0] == 1 ? i : 0); // Incrementing only for occupied cells

        // Check if out of bounds
        if (ledY >= 10 || ledX < 0 || ledX >= 7) return true; // Ensure within bounds

        // Check if position is occupied
        if (shapes[currentShapeIndex][i][0] == 1) {
            if (ledY < 10 && board[ledY][ledX]) return true; // Check if occupied
        }
    }
    return false; // No collision
}






void lockPiece() {
    for (int i = 0; i < 4; i++) {
        int ledX = currentX;
        int ledY = currentY + i;
        
        if (shapes[currentShapeIndex][i][0] == 1) {
            board[ledY][ledX] = true; // Lock the piece into the board
        }
    }
    clearLines(); // Check for full lines
}

void clearLines() {
    for (int i = 0; i < 10; i++) {
        bool fullLine = true;
        for (int j = 0; j < 7; j++) {
            if (!board[i][j]) {
                fullLine = false;
                break;
            }
        }
        
        if (fullLine) {
            // Display colorful line effect before clearing
            for (int effectTime = 0; effectTime < 20; effectTime++) { // Adjust duration of effect
                // Create a colorful moving line effect
                for (int j = 0; j < 7; j++) {
                    int ledIndex = matrix[i][j];
                    // Cycle through colors
                    leds[ledIndex] = CHSV((effectTime * 10 + j * 30) % 256, 255, 255); // Change colors
                }
                FastLED.show(); // Update the LED strip
                delay(10); // Adjust delay for speed of effect
            }

            // Shift lines down
            for (int k = i; k > 0; k--) {
                for (int j = 0; j < 7; j++) {
                    board[k][j] = board[k - 1][j];
                }
            }
            // Clear the top line
            for (int j = 0; j < 7; j++) {
                board[0][j] = false;
            }
        }
    }
}


void drawBoard() {
    clearLEDs();
    // Draw the locked pieces
    for (int i = 0; i < 10; i++) {
        for (int j = 0; j < 7; j++) {
            if (board[i][j]) {
                leds[matrix[i][j]] = CRGB::Red; // Color the locked piece
            }
        }
    }
    // Draw the current piece
    for (int i = 0; i < 4; i++) {
        int ledX = currentX;
        int ledY = currentY + i;
        if (shapes[currentShapeIndex][i][0] == 1 && ledY < 10) {
            leds[matrix[ledY][ledX]] = CRGB::Green; // Color the current piece
        }
    }
}

void clearLEDs() {
    for (int i = 0; i < NUM_LEDS; i++) {
        leds[i] = CRGB::Black; // Clear the LEDs
    }
}
// End of the code

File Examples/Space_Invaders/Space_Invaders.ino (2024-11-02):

/*
 * Space Invaders Game Example for Nova Board
 *
 * Button Connections:
 * - UP Button: connected to pin 2
 * - LEFT Button: connected to pin 3
 * - DOWN Button: connected to pin 4
 * - RIGHT Button: connected to pin 5
 * - RESET Button: connected to pin 6
 *
 * Note: External pull-down resistors are used with the buttons to ensure stable readings.
 *
 * License:
 * This project is open-source hardware and software, released under the MIT License.
 * See the LICENSE file for details.
 */
 
 
 #include <FastLED.h>

#define LED_PIN 22
#define NUM_LEDS 70
#define BRIGHTNESS 10

CRGB leds[NUM_LEDS];

// Define button pins
#define LEFT_BUTTON 3
#define RIGHT_BUTTON 5
#define RESTART_BUTTON 6

// Define game and missile speeds (in milliseconds)
int gameSpeed = 100; // Time interval for starship movement debounce
int missileSpeed = 30; // Time interval for missile movement
int fireInterval = 100; // Time between firing missiles
int enemySpeed = 150; // Speed of enemies moving down (increased for slower movement)
int enemySpeedAdjustment = 50; // Adjusting factor for enemy speed

// Starship position (starts in the middle of the bottom row)
int starshipPosition = 3; // Index for the bottom row (0-6)

// Define LED layout for each row of the matrix
const int rows[10][7] = {
    {69, 50, 49, 30, 29, 10, 9},
    {68, 51, 48, 31, 28, 11, 8},
    {67, 52, 47, 32, 27, 12, 7},
    {66, 53, 46, 33, 26, 13, 6},
    {65, 54, 45, 34, 25, 14, 5},
    {64, 55, 44, 35, 24, 15, 4},
    {63, 56, 43, 36, 23, 16, 3},
    {62, 57, 42, 37, 22, 17, 2},
    {61, 58, 41, 38, 21, 18, 1},
    {60, 59, 40, 39, 20, 19, 0} // Bottom row (starship row)
};

// Enemy positions and colors
const int maxEnemies = 1; // Maximum number of enemies at a time
int enemyRow[maxEnemies]; // Array to hold enemy row positions
int enemyPosition[maxEnemies]; // Array to hold enemy column positions
CRGB enemyColors[maxEnemies]; // Array to hold colors for enemies
bool enemyActive[maxEnemies]; // Array to hold the active state of enemies
unsigned long lastEnemyMoveTime = 0; // Timer for moving enemies

// Missile state
bool missileActive = false;
int missileRow = 8; // Start from row 8 (just above the starship)
int missilePosition = starshipPosition;
unsigned long lastFireTime = 0;
unsigned long lastMissileMoveTime = 0;
unsigned long lastStarshipMoveTime = 0; // Timer for the starship movement debounce

int tailLength = 3; // Length of the missile tail

// Function to clear the starship position
void clearStarship() {
    leds[rows[9][starshipPosition]] = CRGB::Black;
}

// Function to fire a missile
void fireMissile() {
    missileActive = true;
    missileRow = 8; // Start just above the starship in row 8
    missilePosition = starshipPosition;
}

// Function to clear the missile and its tail
void clearMissile() {
    // Clear the missile's position
    if (missileRow < 10) {
        leds[rows[missileRow][missilePosition]] = CRGB::Black; // Clear main missile
    }

    // Clear the tail
    for (int i = 0; i < tailLength; i++) {
        int clearRow = missileRow + i;
        if (clearRow < 10) { // Make sure we don’t go beyond the matrix
            leds[rows[clearRow][missilePosition]] = CRGB::Black; // Clear tail
        }
    }
}

// Function to move the missile upward with a comet-like tail that dims gradually
void moveMissile() {
    if (missileActive) {
        // Clear the previous position of the missile’s tail end
        if (missileRow + tailLength < 10) { // Ensures we clear rows below the missile
            leds[rows[missileRow + tailLength][missilePosition]] = CRGB::Black;
        }

        // Draw the comet-like tail with a dimming effect
        for (int i = 0; i < tailLength; i++) {
            int fadeRow = missileRow + i;
            if (fadeRow < 10) { // Make sure we don’t go beyond the matrix
                leds[rows[fadeRow][missilePosition]] = CRGB::Red;
                leds[rows[fadeRow][missilePosition]].fadeToBlackBy((i + 1) * 50); // Dim further down the tail
            }
        }

        // Move the missile up
        if (missileRow >= 0) {
            leds[rows[missileRow][missilePosition]] = CRGB::Red; // Draw main missile
            missileRow--;
        } else {
            // Clear any remaining tail when the missile reaches the top
            clearMissile(); // Call to clear the missile
            missileActive = false; // Deactivate missile
        }

        // Redraw the starship on the bottom row after updating the missile
        leds[rows[9][starshipPosition]] = CRGB::Blue; // Draw starship
        FastLED.show();
    }
}

// Ensure the starship is drawn after clearing the row in the main loop as well
void drawStarship() {
    leds[rows[9][starshipPosition]] = CRGB::Blue; // Draw starship at its current position
}

// Function to initialize enemies
void initEnemies() {
    // Randomly assign the enemy position between 0 and 6 (valid column positions)
    enemyPosition[0] = random(0, 7); // Random column
    enemyRow[0] = 0; // Start enemy at the top row
    enemyColors[0] = CRGB(random(255), random(255), random(255)); // Assign a random color to the enemy
    enemyActive[0] = true; // Mark enemy as active
}

// Function to draw enemies
void drawEnemies() {
    for (int i = 0; i < maxEnemies; i++) {
        if (enemyActive[i]) {
            leds[rows[enemyRow[i]][enemyPosition[i]]] = enemyColors[i]; // Draw each enemy
        }
    }
}

void clearEnemies() {
    for (int i = 0; i < maxEnemies; i++) {
        if (enemyActive[i]) {
            leds[rows[enemyRow[i]][enemyPosition[i]]] = CRGB::Black; // Clear enemy positions
        }
    }
}

// Function to move enemies down
void moveEnemies() {
    if (millis() - lastEnemyMoveTime >= enemySpeed) {
        clearEnemies(); // Clear current enemy positions

        // Move enemies down
        for (int i = 0; i < maxEnemies; i++) {
            if (enemyActive[i]) {
                enemyRow[i]++;
                if (enemyRow[i] >= 9) { // If the enemy reaches the bottom
                    enemyActive[i] = false; // Mark enemy as inactive (destroyed)
                }
            }
        }

        // Draw the enemies at their new positions
        drawEnemies();
        lastEnemyMoveTime = millis(); // Update last move time
    }
}

// Function to check for missile collisions with enemies
void checkCollisions() {
    for (int i = 0; i < maxEnemies; i++) {
        if (missileActive && enemyActive[i] && missileRow == enemyRow[i] && missilePosition == enemyPosition[i]) {
            enemyActive[i] = false; // Mark enemy as inactive (destroyed)
            clearMissile(); // Clear the missile and its tail
            missileActive = false; // Deactivate the missile
            break; // Exit loop after hit
        }
    }
}
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

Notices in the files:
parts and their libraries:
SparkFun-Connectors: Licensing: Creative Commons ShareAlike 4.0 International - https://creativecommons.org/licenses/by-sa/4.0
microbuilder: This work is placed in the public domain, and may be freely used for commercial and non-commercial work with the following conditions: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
